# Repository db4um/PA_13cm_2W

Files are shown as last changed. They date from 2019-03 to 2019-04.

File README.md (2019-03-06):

# PA 13cm 2W
Small 2W CW PA for the 13cm hamband. Great as a preamp for Eshail2. Size: 25mm x 25mm<br>
When this PA is used for SSB, a maximum output power of 1W (30dBm) is recommended to ensure linearity.<br>
Maximum measured output power was 34dBm (2.5W), but 36 dBm should be possible as well. 

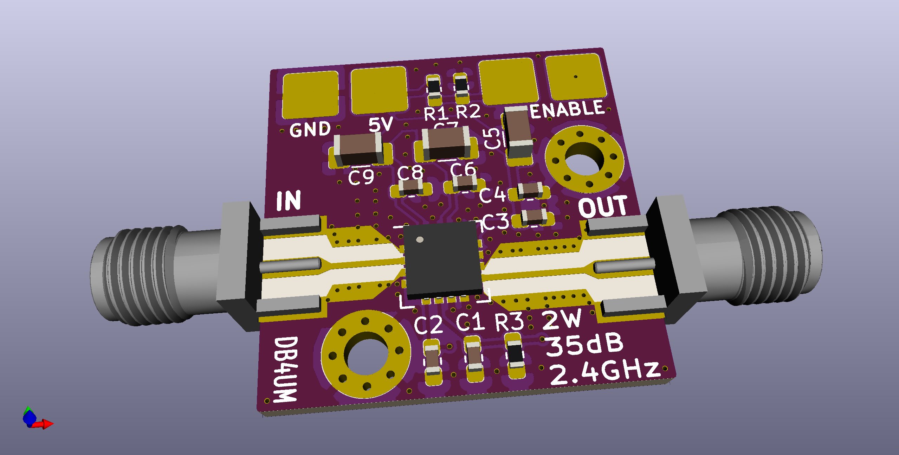
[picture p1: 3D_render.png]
3D rendering of the PCB


The layout is built and impedance matched for the OSHpark 4-Layer process.
You can order the PCB directly from OSHpark: https://oshpark.com/projects/crZvjwqi

**Make sure to mount the PCB on a suitable heatsink**, as the PA dissipates up to 5W. (M2.5 screws)
Using thermal paste is recommended.

## Measured S-Parameter:
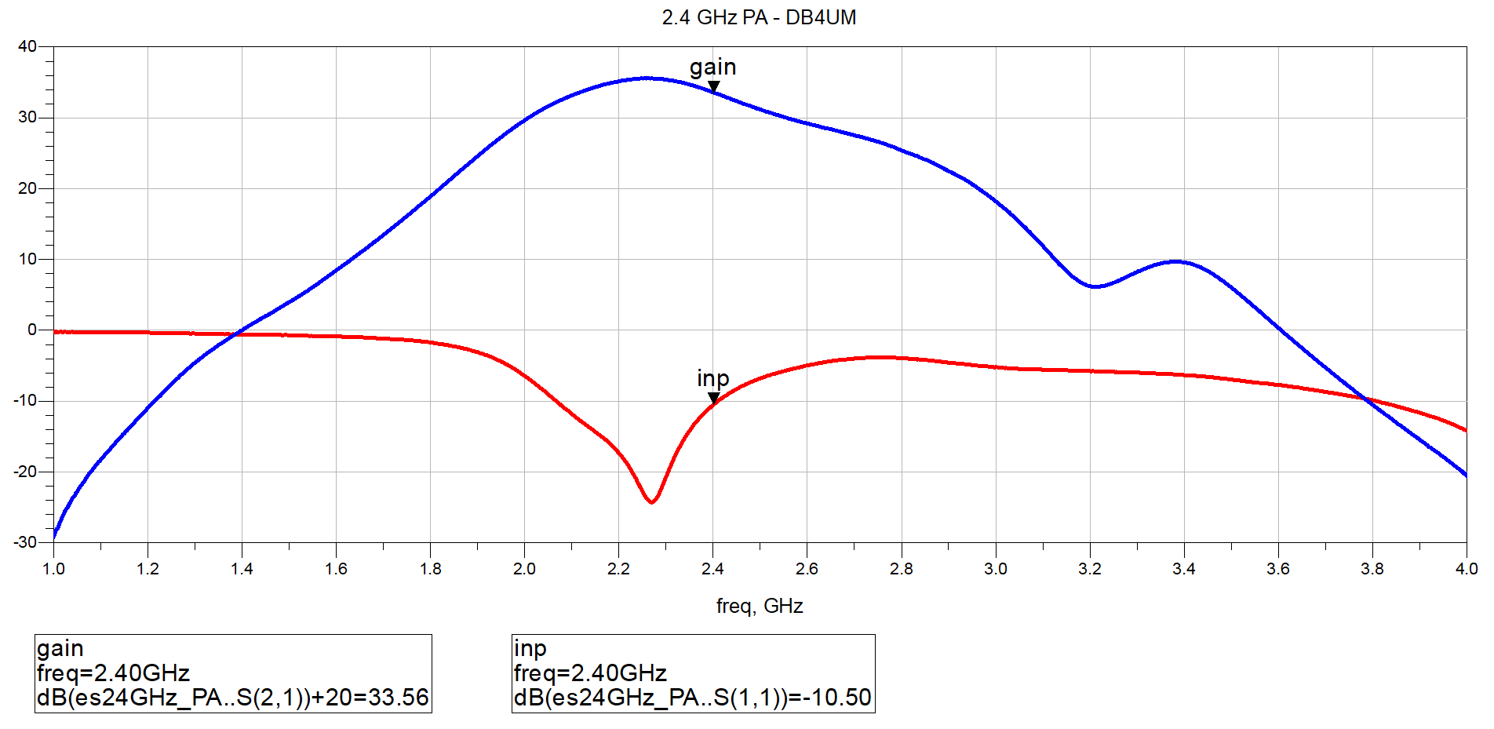
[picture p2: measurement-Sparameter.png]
Plot of the S-parameter


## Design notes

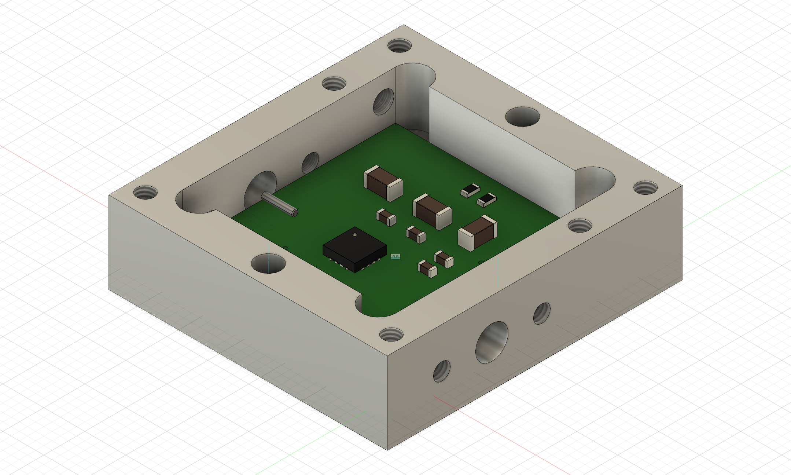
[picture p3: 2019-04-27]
case/case_10mm.png

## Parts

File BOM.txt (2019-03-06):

BOM
2.4 GHz PA - DB4UM
Component Count:15
Ref		Qnty	Value	Part	Datasheet	Description	Vendor
C1, C4, C6, C8	4	3.3n	Device:C Size:0402		~	Unpolarized capacitor	
C2		1	1u	Device:C Size:0402		~	Unpolarized capacitor	
C3		1	100p	Device:C Size:0402		~	Unpolarized capacitor	
C5, C7, C9	3	10u	Device:C Size:1206		~	Unpolarized capacitor	
J1, J2		2	Conn_Coaxial	Connector:Conn_Coaxial	~	coaxial connector SMA	
R1		1	15k	Device:R Size:0402		~	Resistor	
R2		1	10k	Device:R Size:0402		~	Resistor	
R3		1	200k	Device:R			~	DO NOT INSERT	
U1		1	SKY66292-11

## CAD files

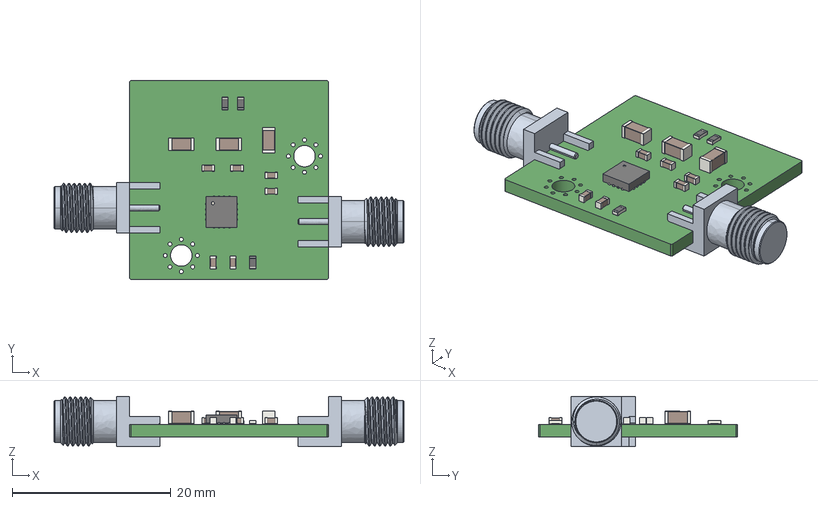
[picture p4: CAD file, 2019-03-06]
2-4GHzPA_step.step
44.0 x 25.0 x 6.35 mm

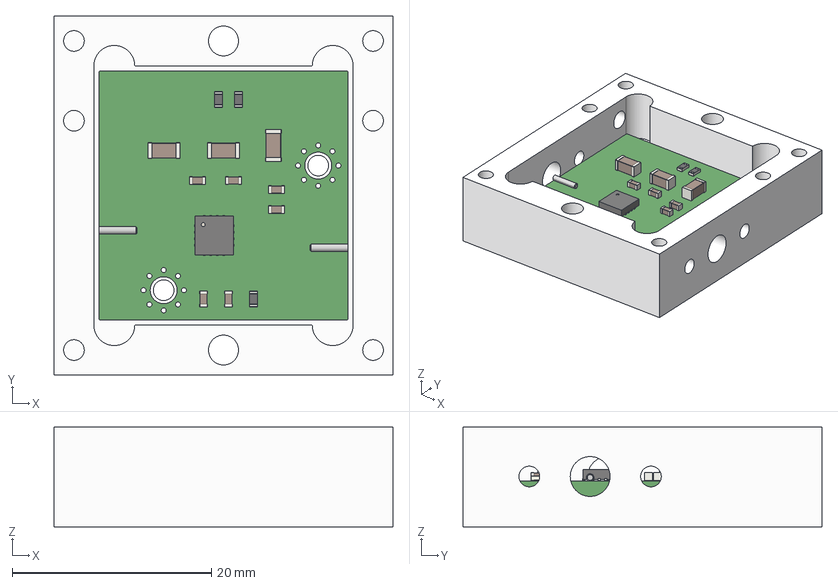
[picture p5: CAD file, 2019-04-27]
case/case_10mm.step
34.0 x 36.0 x 10.0 mm

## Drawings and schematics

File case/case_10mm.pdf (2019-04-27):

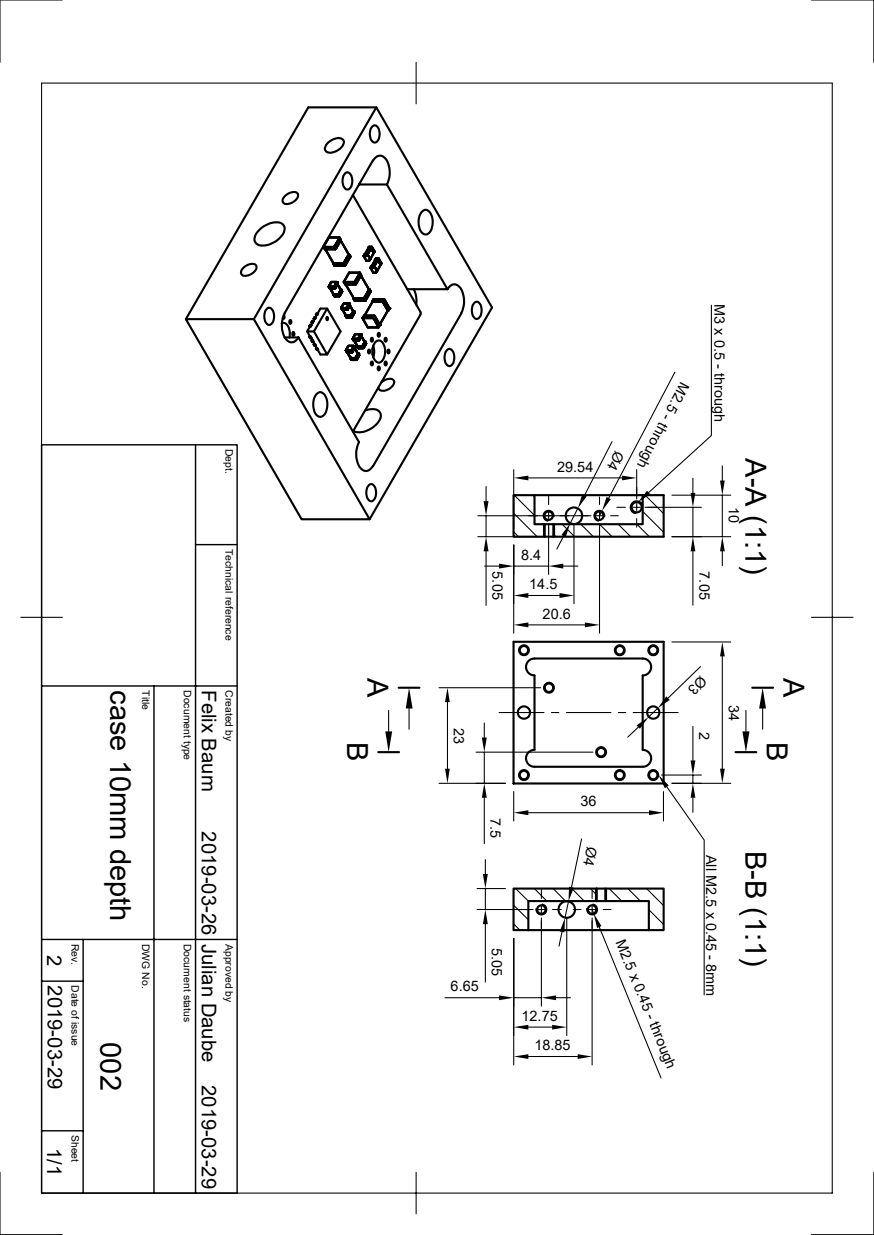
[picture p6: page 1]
x 0.45 - through; rough

Dept. Technical reference Created by Approved by Title DWG No. Document type Document status Rev. Date of issue Sheet 2019-03-29

2 2019-03-29 2019-03-26 1/1 002 case 10mm depth Julian Daube Felix Baum All M2.5 x 0.45 - 8mm

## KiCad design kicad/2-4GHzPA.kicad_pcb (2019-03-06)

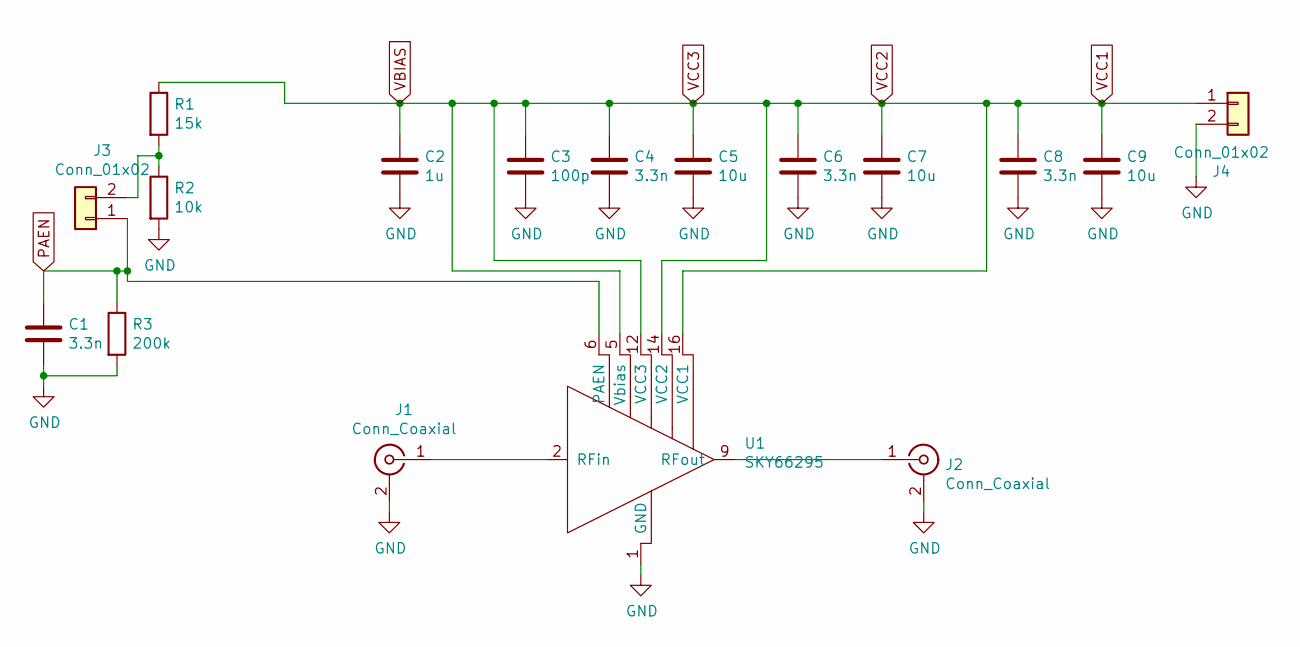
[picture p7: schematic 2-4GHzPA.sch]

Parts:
C1, C4, C6, C8: 3.3n; C_0603_1608Metric_Pad1.05x0.95mm_HandSolder
C2: 1u; C_0603_1608Metric_Pad1.05x0.95mm_HandSolder
C3: 100p; C_0603_1608Metric_Pad1.05x0.95mm_HandSolder
C5, C7, C9: 10u; C_1206_3216Metric_Pad1.42x1.75mm_HandSolder
J1, J2: Conn_Coaxial; SMA_Samtec_SMA-J-P-H-ST-EM1_EdgeMount
J3, J4: Conn_01x02; PinHeader_1x02_P2.54mm_Vertical
R1: 15k; R_0603_1608Metric_Pad1.05x0.95mm_HandSolder
R2: 10k; R_0603_1608Metric_Pad1.05x0.95mm_HandSolder
R3: 200k; R_0603_1608Metric_Pad1.05x0.95mm_HandSolder
U1: SKY66295; QFN-16_EP_5.3x5.3_Pitch0.8mm

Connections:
GND: C1.2, C2.2, C3.2, C4.2, C5.2, C6.2, C7.2, C8.2, C9.2, J1.2 (Ext), J2.2 (Ext), J4.2, R2.2, R3.2, U1.1 (GND), U1.3 (GND), U1.4 (GND), U1.7 (GND), U1.8 (GND), U1.10 (GND), U1.11 (GND), U1.13 (GND), U1.15 (GND), U1.17 (GND)
unnamed: J1.1 (In), U1.2 (RFin)
unnamed: J2.1 (In), U1.9 (RFout)
unnamed: J3.2, R1.2, R2.1
PAEN: C1.1, J3.1, R3.1, U1.6 (PAEN)
VBIAS: C2.1, C3.1, C4.1, C5.1, C6.1, C7.1, C8.1, C9.1, J4.1, R1.1, U1.5 (Vbias), U1.12 (VCC3), U1.14 (VCC2), U1.16 (VCC1)

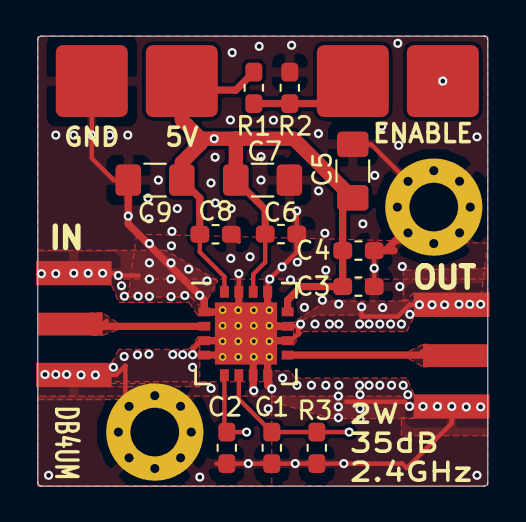
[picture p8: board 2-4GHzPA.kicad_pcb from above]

Board: 4 copper layers, 25.0 x 25.0 mm, 17 parts (0 on the bottom side), 6 nets.

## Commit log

2019-03-06 first real commit
    added project files
    [2-4GHzPA.kicad_pcb, 2-4GHzPA.sch, 2-4GHzPA_step.step]
2019-03-06 Create BOM.txt.txt
    bom also included as a txt
2019-03-06 small bom fix
    corrected ic
2019-03-06 bom ic fixed
2019-03-14 missing kicad files
    [2-4GHzPA.kicad_pcb]
2019-04-27 added case
    [case_10mm.step]
